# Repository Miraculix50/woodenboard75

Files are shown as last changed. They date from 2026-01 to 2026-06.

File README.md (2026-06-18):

# Wooden Keyboard
An ISO-DE 75 % keyboard with a wooden case and knob.

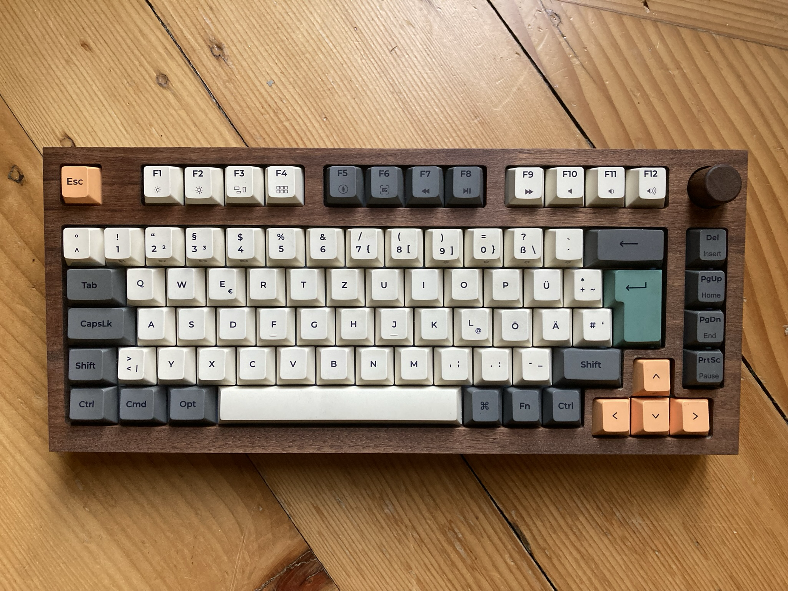
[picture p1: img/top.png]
Wooden keyboard


It's definetly not perfect and could be optimized, but for me it works.
Feel free to [build it yourself](#parts).

## Parts
### PCB
* PCB (when ordering, upload the [gerber files](https://github.com/Miraculix50/woodenboard75/blob/09ee0a02b5c7668ce41eeeb4c7d635bece270f4e/PCB/kicad/production/keyboard.zip))
* [0xcb Helios with MillMax pins and IC-Sockets (MCU) x1](https://keeb.supply/products/0xcb-helios?variant=f57eeaae-cae7-4b2d-b5ac-bef47a280a65)
* [Hotswap sockets x83](https://keeb.supply/products/kailh-hotswap-sockets)
* [THT diodes x84](https://keeb.supply/products/tht-diodes)
* [Reset button x1](https://keeb.supply/products/2-pin-reset-button)
* [EC11 rotary encoder x1](https://keeb.supply/products/pec11r-4220f-s0024)

### Keys
* [Switches x83](https://keeb.supply/products/invokeys-matcha-reserve-switches)
* [Keycaps for 75%-layout](https://monacokeys.de/products/monacokeys-mk-retro-beige-pbt-keycap-set)

### Wooden case & knob (files avaible in [CAD folder](/CAD))
* Bar magnets (4mm diameter + 8mm height) x8
* Top case
* Bottom case
* Knob

> All links are just examples.

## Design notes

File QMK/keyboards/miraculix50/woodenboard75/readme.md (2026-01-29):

# miraculix50/woodenkeys75

*A wooden ISO-DE 75 % keyboard with an EC11 Rotary Encoder.*

* Keyboard Maintainer: [Miraculix50](https://github.com/Miraculix50)
* Hardware Supported: *Custom PCB with 0xcb Helios Microcontroller*
* Hardware Availability: https://keeb.supply/products/0xcb-helios

Make example for this keyboard (after setting up your build environment):

    make miraculix50/woodenkeys75:default

Flashing example for this keyboard:

    make miraculix50/woodenkeys75:default:flash

See the [build environment setup](https://docs.qmk.fm/#/getting_started_build_tools) and the [make instructions](https://docs.qmk.fm/#/getting_started_make_guide) for more information. Brand new to QMK? Start with our [Complete Newbs Guide](https://docs.qmk.fm/#/newbs).

## Bootloader

Enter the bootloader in 2 ways:

* **Physical reset button**: Briefly press the button under the CapsLock key
* **Keycode in layout**: Press the key mapped to `QK_BOOT` (FN + ESC)

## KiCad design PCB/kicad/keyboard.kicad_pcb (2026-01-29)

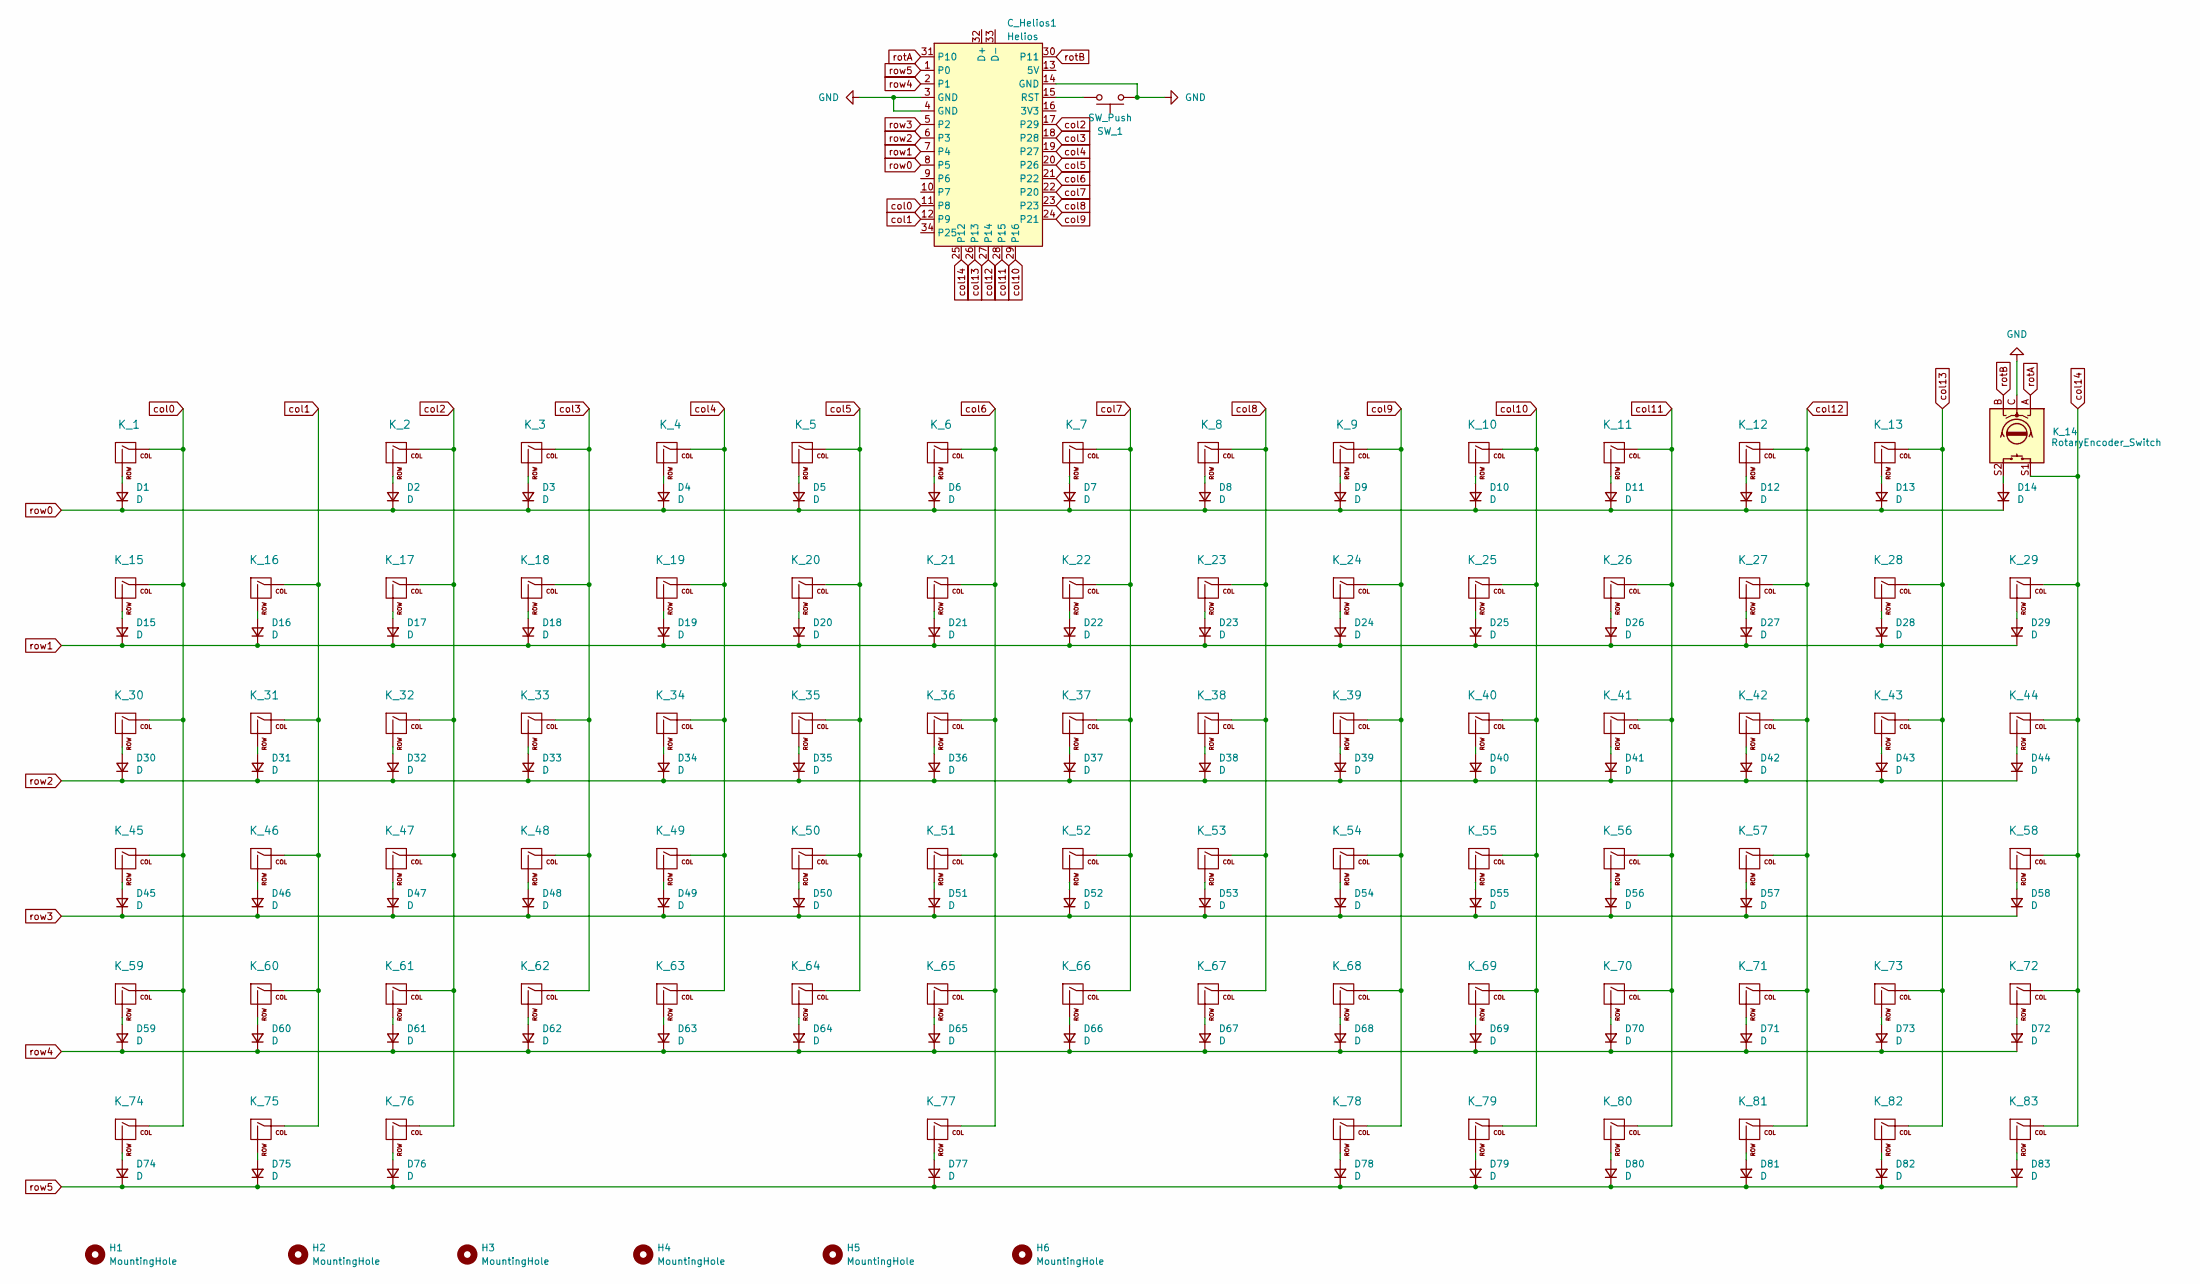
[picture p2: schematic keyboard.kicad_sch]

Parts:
C_Helios1: Helios; Helios_AH_USBdn
D1, D2, D3, D4, D5, D6, D7, D8, D9, D10, D11, D12, D13, D14, D15, D16, D17, D18, D19, D20, D21, D22, D23, D24, D25, D26, D27, D28, D29, D30, D31, D32, D33, D34, D35, D36, D37, D38, D39, D40, D41, D42, D43, D44, D45, D46, D47, D48, D49, D50, D51, D52, D53, D54, D55, D56, D57, D58, D59, D60, D61, D62, D63, D64, D65, D66, D67, D68, D69, D70, D71, D72, D73, D74, D75, D76, D77, D78, D79, D80, D81, D82, D83: D; D_DO-35_SOD27_P7.62mm_Horizontal
H1, H2, H3, H4, H5, H6: MountingHole; MountingHole_3.2mm_M3_ISO14580
K_1, K_2, K_3, K_4, K_5, K_6, K_7, K_8, K_9, K_10, K_11, K_12, K_13, K_15, K_16, K_17, K_18, K_19, K_20, K_21, K_22, K_23, K_24, K_25, K_26, K_27, K_29, K_31, K_32, K_33, K_34, K_35, K_36, K_37, K_38, K_39, K_40, K_41, K_42, K_44, K_46, K_47, K_48, K_49, K_50, K_51, K_52, K_53, K_54, K_55, K_56, K_57, K_58, K_60, K_61, K_62, K_63, K_64, K_65, K_66, K_67, K_68, K_69, K_70, K_72, K_73, K_78, K_79, K_80, K_81, K_82, K_83: KEYSW; MX-Hotswap-1U
K_14: RotaryEncoder_Switch; Bourns-PEC11R-4220F-S0024-0-0-0
K_28: KEYSW; MX-Hotswap-2U
K_30: KEYSW; MX-Hotswap-1.5U
K_43: KEYSW; MX-Hotswap-ISO-Rotated
K_45, K_71: KEYSW; MX-Hotswap-1.75U
K_59, K_74, K_75, K_76: KEYSW; MX-Hotswap-1.25U
K_77: KEYSW; MX-Hotswap-6.25U
SW_1: SW_Push; SW_PUSH_1P1T_6x3.5mm_H5.0_APEM_MJTP1250

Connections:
GND: C_Helios1.3 (GND), C_Helios1.4 (GND), C_Helios1.14 (GND), K_14.C, SW_1.2
unnamed: C_Helios1.15 (RST), SW_1.1
unnamed: D1.2 (A), K_1.2 (ROW)
unnamed: D2.2 (A), K_2.2 (ROW)
unnamed: D3.2 (A), K_3.2 (ROW)
unnamed: D4.2 (A), K_4.2 (ROW)
unnamed: D5.2 (A), K_5.2 (ROW)
unnamed: D6.2 (A), K_6.2 (ROW)
unnamed: D7.2 (A), K_7.2 (ROW)
unnamed: D8.2 (A), K_8.2 (ROW)
unnamed: D9.2 (A), K_9.2 (ROW)
unnamed: D10.2 (A), K_10.2 (ROW)
unnamed: D11.2 (A), K_11.2 (ROW)
unnamed: D12.2 (A), K_12.2 (ROW)
unnamed: D13.2 (A), K_13.2 (ROW)
unnamed: D14.2 (A), K_14.S2
unnamed: D15.2 (A), K_15.2 (ROW)
unnamed: D16.2 (A), K_16.2 (ROW)
unnamed: D17.2 (A), K_17.2 (ROW)
unnamed: D18.2 (A), K_18.2 (ROW)
unnamed: D19.2 (A), K_19.2 (ROW)
unnamed: D20.2 (A), K_20.2 (ROW)
unnamed: D21.2 (A), K_21.2 (ROW)
unnamed: D22.2 (A), K_22.2 (ROW)
unnamed: D23.2 (A), K_23.2 (ROW)
unnamed: D24.2 (A), K_24.2 (ROW)
unnamed: D25.2 (A), K_25.2 (ROW)
unnamed: D26.2 (A), K_26.2 (ROW)
unnamed: D27.2 (A), K_27.2 (ROW)
unnamed: D28.2 (A), K_28.2 (ROW)
unnamed: D29.2 (A), K_29.2 (ROW)
unnamed: D30.2 (A), K_30.2 (ROW)
unnamed: D31.2 (A), K_31.2 (ROW)
unnamed: D32.2 (A), K_32.2 (ROW)
unnamed: D33.2 (A), K_33.2 (ROW)
unnamed: D34.2 (A), K_34.2 (ROW)
unnamed: D35.2 (A), K_35.2 (ROW)
unnamed: D36.2 (A), K_36.2 (ROW)
unnamed: D37.2 (A), K_37.2 (ROW)
unnamed: D38.2 (A), K_38.2 (ROW)
unnamed: D39.2 (A), K_39.2 (ROW)
unnamed: D40.2 (A), K_40.2 (ROW)
unnamed: D41.2 (A), K_41.2 (ROW)
unnamed: D42.2 (A), K_42.2 (ROW)
unnamed: D43.2 (A), K_43.2 (ROW)
unnamed: D44.2 (A), K_44.2 (ROW)
unnamed: D45.2 (A), K_45.2 (ROW)
unnamed: D46.2 (A), K_46.2 (ROW)
unnamed: D47.2 (A), K_47.2 (ROW)
unnamed: D48.2 (A), K_48.2 (ROW)
unnamed: D49.2 (A), K_49.2 (ROW)
unnamed: D50.2 (A), K_50.2 (ROW)
unnamed: D51.2 (A), K_51.2 (ROW)
unnamed: D52.2 (A), K_52.2 (ROW)
unnamed: D53.2 (A), K_53.2 (ROW)
unnamed: D54.2 (A), K_54.2 (ROW)
unnamed: D55.2 (A), K_55.2 (ROW)
unnamed: D56.2 (A), K_56.2 (ROW)
unnamed: D57.2 (A), K_57.2 (ROW)
unnamed: D58.2 (A), K_58.2 (ROW)
unnamed: D59.2 (A), K_59.2 (ROW)
unnamed: D60.2 (A), K_60.2 (ROW)
unnamed: D61.2 (A), K_61.2 (ROW)
unnamed: D62.2 (A), K_62.2 (ROW)
unnamed: D63.2 (A), K_63.2 (ROW)
unnamed: D64.2 (A), K_64.2 (ROW)
unnamed: D65.2 (A), K_65.2 (ROW)
unnamed: D66.2 (A), K_66.2 (ROW)
unnamed: D67.2 (A), K_67.2 (ROW)
unnamed: D68.2 (A), K_68.2 (ROW)
unnamed: D69.2 (A), K_69.2 (ROW)
unnamed: D70.2 (A), K_70.2 (ROW)
unnamed: D71.2 (A), K_71.2 (ROW)
unnamed: D72.2 (A), K_72.2 (ROW)
unnamed: D73.2 (A), K_73.2 (ROW)
unnamed: D74.2 (A), K_74.2 (ROW)
unnamed: D75.2 (A), K_75.2 (ROW)
unnamed: D76.2 (A), K_76.2 (ROW)
unnamed: D77.2 (A), K_77.2 (ROW)
unnamed: D78.2 (A), K_78.2 (ROW)
unnamed: D79.2 (A), K_79.2 (ROW)
unnamed: D80.2 (A), K_80.2 (ROW)
unnamed: D81.2 (A), K_81.2 (ROW)
unnamed: D82.2 (A), K_82.2 (ROW)
unnamed: D83.2 (A), K_83.2 (ROW)
col0: C_Helios1.11 (P8), K_1.1 (COL), K_15.1 (COL), K_30.1 (COL), K_45.1 (COL), K_59.1 (COL), K_74.1 (COL)
col1: C_Helios1.12 (P9), K_16.1 (COL), K_31.1 (COL), K_46.1 (COL), K_60.1 (COL), K_75.1 (COL)
col2: C_Helios1.17 (P29), K_2.1 (COL), K_17.1 (COL), K_32.1 (COL), K_47.1 (COL), K_61.1 (COL), K_76.1 (COL)
col3: C_Helios1.18 (P28), K_3.1 (COL), K_18.1 (COL), K_33.1 (COL), K_48.1 (COL), K_62.1 (COL)
col4: C_Helios1.19 (P27), K_4.1 (COL), K_19.1 (COL), K_34.1 (COL), K_49.1 (COL), K_63.1 (COL)
col5: C_Helios1.20 (P26), K_5.1 (COL), K_20.1 (COL), K_35.1 (COL), K_50.1 (COL), K_64.1 (COL)
col6: C_Helios1.21 (P22), K_6.1 (COL), K_21.1 (COL), K_36.1 (COL), K_51.1 (COL), K_65.1 (COL), K_77.1 (COL)
col7: C_Helios1.22 (P20), K_7.1 (COL), K_22.1 (COL), K_37.1 (COL), K_52.1 (COL), K_66.1 (COL)
col8: C_Helios1.23, K_8.1 (COL), K_23.1 (COL), K_38.1 (COL), K_53.1 (COL), K_67.1 (COL)
col9: C_Helios1.24 (P21), K_9.1 (COL), K_24.1 (COL), K_39.1 (COL), K_54.1 (COL), K_68.1 (COL), K_78.1 (COL)
col10: C_Helios1.29 (P16), K_10.1 (COL), K_25.1 (COL), K_40.1 (COL), K_55.1 (COL), K_69.1 (COL), K_79.1 (COL)
col11: C_Helios1.28 (P15), K_11.1 (COL), K_26.1 (COL), K_41.1 (COL), K_56.1 (COL), K_70.1 (COL), K_80.1 (COL)
col12: C_Helios1.27 (P14), K_12.1 (COL), K_27.1 (COL), K_42.1 (COL), K_57.1 (COL), K_71.1 (COL), K_81.1 (COL)
col13: C_Helios1.26 (P13), K_13.1 (COL), K_28.1 (COL), K_43.1 (COL), K_73.1 (COL), K_82.1 (COL)
col14: C_Helios1.25 (P12), K_14.S1, K_29.1 (COL), K_44.1 (COL), K_58.1 (COL), K_72.1 (COL), K_83.1 (COL)
rotA: C_Helios1.31 (P10), K_14.A
rotB: C_Helios1.30 (P11), K_14.B
row0: C_Helios1.8 (P5), D1.1 (K), D2.1 (K), D3.1 (K), D4.1 (K), D5.1 (K), D6.1 (K), D7.1 (K), D8.1 (K), D9.1 (K), D10.1 (K), D11.1 (K), D12.1 (K), D13.1 (K), D14.1 (K)
row1: C_Helios1.7 (P4), D15.1 (K), D16.1 (K), D17.1 (K), D18.1 (K), D19.1 (K), D20.1 (K), D21.1 (K), D22.1 (K), D23.1 (K), D24.1 (K), D25.1 (K), D26.1 (K), D27.1 (K), D28.1 (K), D29.1 (K)
row2: C_Helios1.6 (P3), D30.1 (K), D31.1 (K), D32.1 (K), D33.1 (K), D34.1 (K), D35.1 (K), D36.1 (K), D37.1 (K), D38.1 (K), D39.1 (K), D40.1 (K), D41.1 (K), D42.1 (K), D43.1 (K), D44.1 (K)
row3: C_Helios1.5 (P2), D45.1 (K), D46.1 (K), D47.1 (K), D48.1 (K), D49.1 (K), D50.1 (K), D51.1 (K), D52.1 (K), D53.1 (K), D54.1 (K), D55.1 (K), D56.1 (K), D57.1 (K), D58.1 (K)
row4: C_Helios1.2 (P1), D59.1 (K), D60.1 (K), D61.1 (K), D62.1 (K), D63.1 (K), D64.1 (K), D65.1 (K), D66.1 (K), D67.1 (K), D68.1 (K), D69.1 (K), D70.1 (K), D71.1 (K), D72.1 (K), D73.1 (K)
row5: C_Helios1.1 (P0), D74.1 (K), D75.1 (K), D76.1 (K), D77.1 (K), D78.1 (K), D79.1 (K), D80.1 (K), D81.1 (K), D82.1 (K), D83.1 (K)

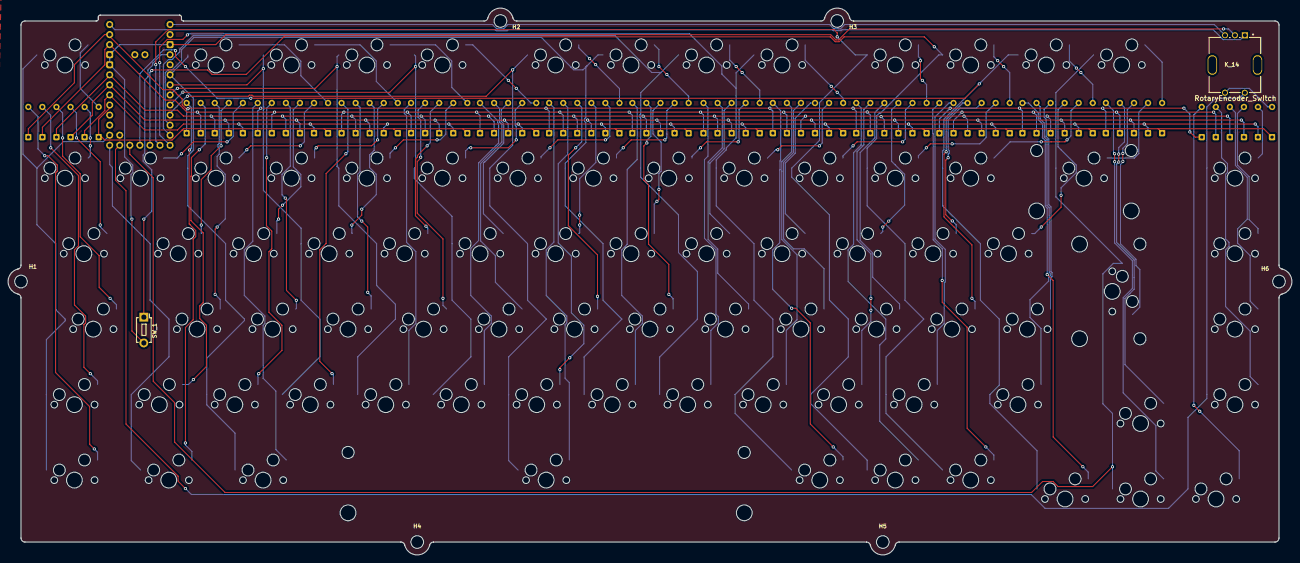
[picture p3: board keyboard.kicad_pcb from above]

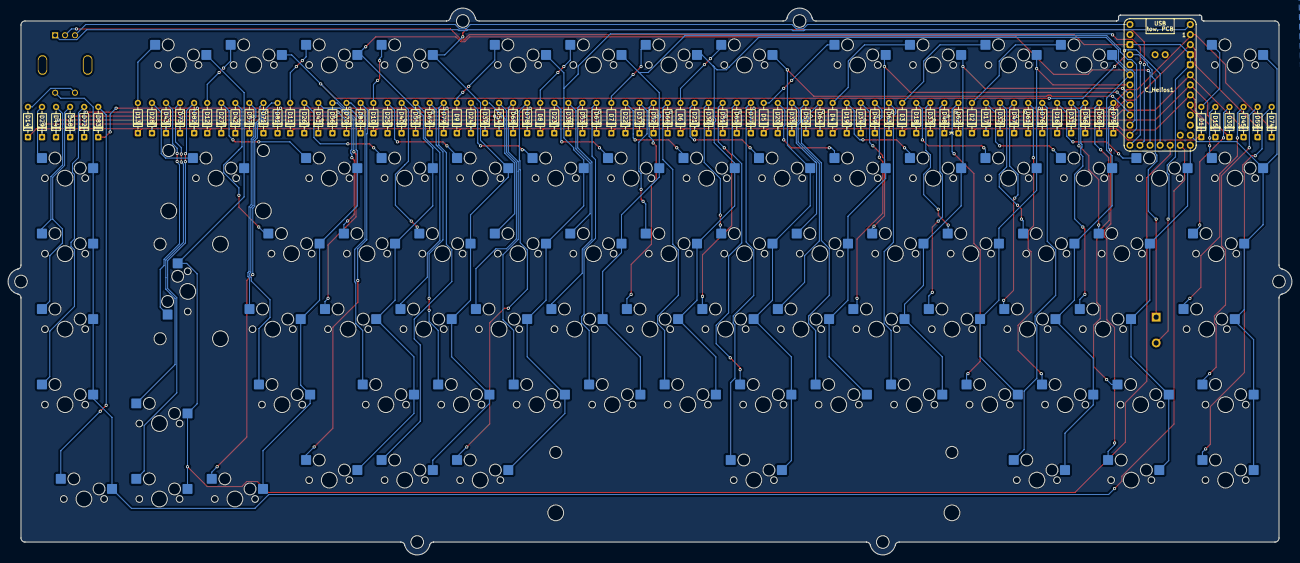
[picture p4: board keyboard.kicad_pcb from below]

Board: 2 copper layers, 324.0 x 138.0 mm, 174 parts (166 on the bottom side), 108 nets.

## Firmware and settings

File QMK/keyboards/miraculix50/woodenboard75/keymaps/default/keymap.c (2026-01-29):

// Copyright 2023 QMK
// SPDX-License-Identifier: GPL-2.0-or-later

#include QMK_KEYBOARD_H

enum layers {
    _BASE,
    _FN
};

const uint16_t PROGMEM keymaps[][MATRIX_ROWS][MATRIX_COLS] = {
     /*
     * ┌───┐   ┌───┬───┬───┬───┐ ┌───┬───┬───┬───┐ ┌───┬───┬───┬───┐ ┌───┐
     * │Esc│   │F1 │F2 │F3 │F4 │ │F5 │F6 │F7 │F8 │ │F9 │F10│F11│F12│ │Mut│
     * └───┘   └───┴───┴───┴───┘ └───┴───┴───┴───┘ └───┴───┴───┴───┘ └───┘
     * ┌───┬───┬───┬───┬───┬───┬───┬───┬───┬───┬───┬───┬───┬───────┐ ┌───┐
     * │ ` │ 1 │ 2 │ 3 │ 4 │ 5 │ 6 │ 7 │ 8 │ 9 │ 0 │ ß │ ´ │ Backsp│ │Del│
     * ├───┴─┬─┴─┬─┴─┬─┴─┬─┴─┬─┴─┬─┴─┬─┴─┬─┴─┬─┴─┬─┴─┬─┴─┬─┴─┬─────┤ ├───┤
     * │ Tab │ Q │ W │ E │ R │ T │ Z │ U │ I │ O │ P │ ü │ + │     │ │PgU│
     * ├─────┴┬──┴┬──┴┬──┴┬──┴┬──┴┬──┴┬──┴┬──┴┬──┴┬──┴┬──┴┬──┴┐ Ent│ ├───┤
     * │ Caps │ A │ S │ D │ F │ G │ H │ J │ K │ L │ Ö │ Ä │ # │    │ │PgD│
     * ├────┬─┴─┬─┴─┬─┴─┬─┴─┬─┴─┬─┴─┬─┴─┬─┴─┬─┴─┬─┴─┬─┴─┬─┴───┴┬───┘ ├───┤
     * │Shft│ < │ Y │ X │ C │ V │ B │ N │ M │ , │ . │ - │ Shift│┌───┐│Hom│
     * ├────┼───┴┬──┴─┬─┴───┴───┴───┴───┴───┴──┬┴──┬┴──┬┴──┬───┘│ ↑ │└───┘
     * │Ctrl│Opt │Cmd │         Space          │Cmd│FnL│Ctl│┌───┼───┼───┐
     * └────┴────┴────┴────────────────────────┴───┴───┴───┘│ ← │ ↓ │ → │
     *                                                      └───┴───┴───┘
     */
    [_BASE] = LAYOUT_75_iso(
        KC_ESC,           KC_F1,   KC_F2,   KC_F3,   KC_F4,       KC_F5,   KC_F6,   KC_F7,   KC_F8,        KC_F9,   KC_F10,  KC_F11,  KC_F12,  KC_MUTE,
        KC_NUBS, KC_1,    KC_2,    KC_3,    KC_4,    KC_5,    KC_6,    KC_7,    KC_8,    KC_9,    KC_0,    KC_MINS, KC_EQL,  KC_BSPC,          KC_DEL,
        KC_TAB,  KC_Q,    KC_W,    KC_E,    KC_R,    KC_T,    KC_Y,    KC_U,    KC_I,    KC_O,    KC_P,    KC_LBRC, KC_RBRC, KC_ENT,           KC_PGUP,
        KC_CAPS, KC_A,    KC_S,    KC_D,    KC_F,    KC_G,    KC_H,    KC_J,    KC_K,    KC_L,    KC_SCLN, KC_QUOT, KC_NUHS,                   KC_PGDN,
        KC_LSFT, KC_GRV,  KC_Z,    KC_X,    KC_C,    KC_V,    KC_B,    KC_N,    KC_M,    KC_COMM, KC_DOT,  KC_SLSH,          KC_RSFT, KC_UP,   KC_HOME,
        KC_LCTL, KC_LOPT, KC_LCMD,                            KC_SPC,                             KC_RCMD, MO(_FN), KC_RCTL, KC_LEFT, KC_DOWN, KC_RGHT
    ),

    /*
    * ┌───┐   ┌───┬───┬───┬───┐ ┌───┬───┬───┬───┐ ┌───┬───┬───┬───┐ ┌───┐
    * │QKB│   │   │   │Dsk│   │ │   │   │Prv│Ply│ │Nxt│Mut│VDo│VUp│ │   │
    * └───┘   └───┴───┴───┴───┘ └───┴───┴───┴───┘ └───┴───┴───┴───┘ └───┘
    * ┌───┬───┬───┬───┬───┬───┬───┬───┬───┬───┬───┬───┬───┬───────┐ ┌───┐
    * │   │   │   │   │   │   │   │   │   │   │   │   │   │ Backsp│ │   │
    * ├───┴─┬─┴─┬─┴─┬─┴─┬─┴─┬─┴─┬─┴─┬─┴─┬─┴─┬─┴─┬─┴─┬─┴─┬─┴─┬─────┤ ├───┤
    * │     │   │   │   │   │   │   │   │   │   │   │   │   │     │ │   │
    * ├─────┴┬──┴┬──┴┬──┴┬──┴┬──┴┬──┴┬──┴┬──┴┬──┴┬──┴┬──┴┬──┴┐ Ent│ ├───┤
    * │      │   │   │   │   │   │   │   │   │LPd│   │   │   │    │ │   │
    * ├────┬─┴─┬─┴─┬─┴─┬─┴─┬─┴─┬─┴─┬─┴─┬─┴─┬─┴─┬─┴─┬─┴─┬─┴───┴┬───┘ ├───┤
    * │    │   │   │   │   │   │   │   │   │   │   │   │ Shift│┌───┐│   │
    * ├────┼───┴┬──┴─┬─┴───┴───┴───┴───┴───┴──┬┴──┬┴──┬┴──┬───┘│ ↑ │└───┘
    * │    │    │    │                        │   │   │   │┌───┼───┼───┐
    * └────┴────┴────┴────────────────────────┴───┴───┴───┘│ ← │ ↓ │ → │
    *                                                      └───┴───┴───┘
    */
   [_FN] = LAYOUT_75_iso(
       QK_BOOT,          _______, _______, KC_MCTL, _______,     _______, _______, KC_MPRV, KC_MPLY,      KC_MNXT, KC_MUTE, KC_VOLD, KC_VOLU, _______,
       _______, _______, _______, _______, _______, _______, _______, _______, _______, _______, _______, _______, _______, _______,          _______,
       _______, _______, _______, _______, _______, _______, _______, _______, _______, _______, _______, _______, _______, _______,          _______,
       _______, _______, _______, _______, _______, _______, _______, _______, _______, KC_LPAD, _______, _______, _______,                   _______,
       _______, _______, _______, _______, _______, _______, _______, _______, _______, _______, _______, _______,          _______, _______, _______,
       _______, _______, _______,                            _______,                            _______, _______, _______, _______, _______, _______
   )
};

#if defined(ENCODER_MAP_ENABLE)
const uint16_t PROGMEM encoder_map[][NUM_ENCODERS][NUM_DIRECTIONS] = {
    [_BASE] = { ENCODER_CCW_CW(KC_VOLD, KC_VOLU) },
    [_FN] = { ENCODER_CCW_CW(_______, _______) },
};
#endif

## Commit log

2026-07-26 Remove unused CAD files
    [Plate.dxf, RotaryEncoder.step, ai03Plate.dxf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]
2026-07-26 Add KiCad history directory to gitignore
2026-10-19 Seperate KiCad libraries from project folder
2026-10-20 Restructure qmk and cad folder
